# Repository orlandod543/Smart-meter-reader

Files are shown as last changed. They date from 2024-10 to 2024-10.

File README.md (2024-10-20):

# **P1 Reader Board for Smart Meters**

This is a P1 reader board that I built to measure electricity and gas from smart meters typically found in the Netherlands. It is designed to be a simple, DIY alternative to commercially available devices, fully compatible with Home Assistant and ESPHome, while being easy to assemble at home.

## **Key Features**
- **Powered directly by the smart meter**: No external power supply is needed; the board is powered from the P1 port of your meter.
- **Wi-Fi Connectivity**: The board connects to your local network via Wi-Fi.
- **Home Assistant Integration**: The design is fully compatible with Home Assistant for easy monitoring and automation.
- **ESPHome Compatibility**: It uses the DSMR (Dutch Smart Meter Requirements) component of ESPHome for simple configuration.
- **Easy DIY Assembly**: The PCB is designed for ease of assembly, allowing you to solder it at home in a few hours.

Additionally, the board includes an optional **DHT22 sensor** to monitor the temperature and humidity inside your electrical cabinet.

At the moment an example of the script to be used is not in this repository. Please go to https://esphome.io/components/sensor/dsmr.html for more details on how to create it. 

## **Getting Started**
- Assemble the PCB using the provided schematics.
- Create a ESPHome script following the instructions here: https://esphome.io/components/sensor/dsmr.html
- Flash the ESPHome firmware with your network details.
- Integrate with Home Assistant or any other compatible home automation platform.

## **License Information**

This hardware design is licensed under the **CERN Open Hardware License Strongly Reciprocal (CERN-OHL-S) v2.0**. This ensures that all modifications and derivative works are shared under the same open-source terms.

### **Summary of License Terms**
1. **You are free to**:
   - Use the design files for any purpose.
   - Modify the design, as long as you share your modifications under the same license.
   - Manufacture products based on this design.

2. **Conditions**:
   - You must give appropriate credit, including a link to the original design and this license.
   - If you modify the design and distribute the modified work (either as hardware or design files), you must share the modifications under the same license.

3. **Limitations**:
   - This license ensures that any modifications or derivatives of this design remain open-source.

For the full terms, please refer to the LICENSE.txt file.

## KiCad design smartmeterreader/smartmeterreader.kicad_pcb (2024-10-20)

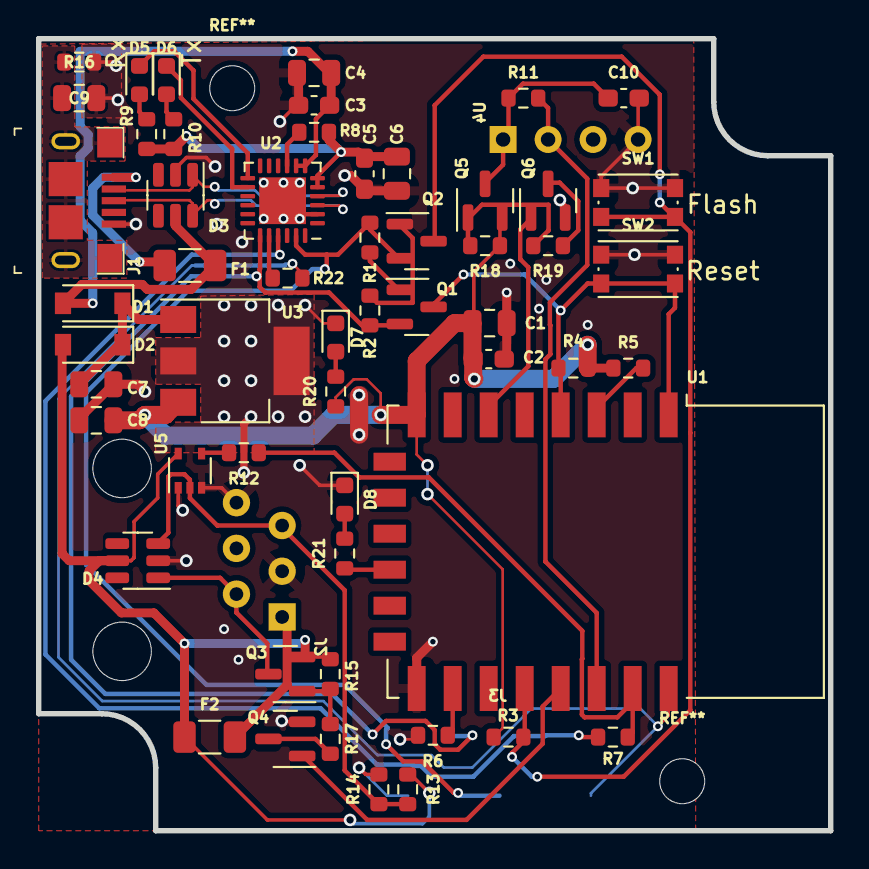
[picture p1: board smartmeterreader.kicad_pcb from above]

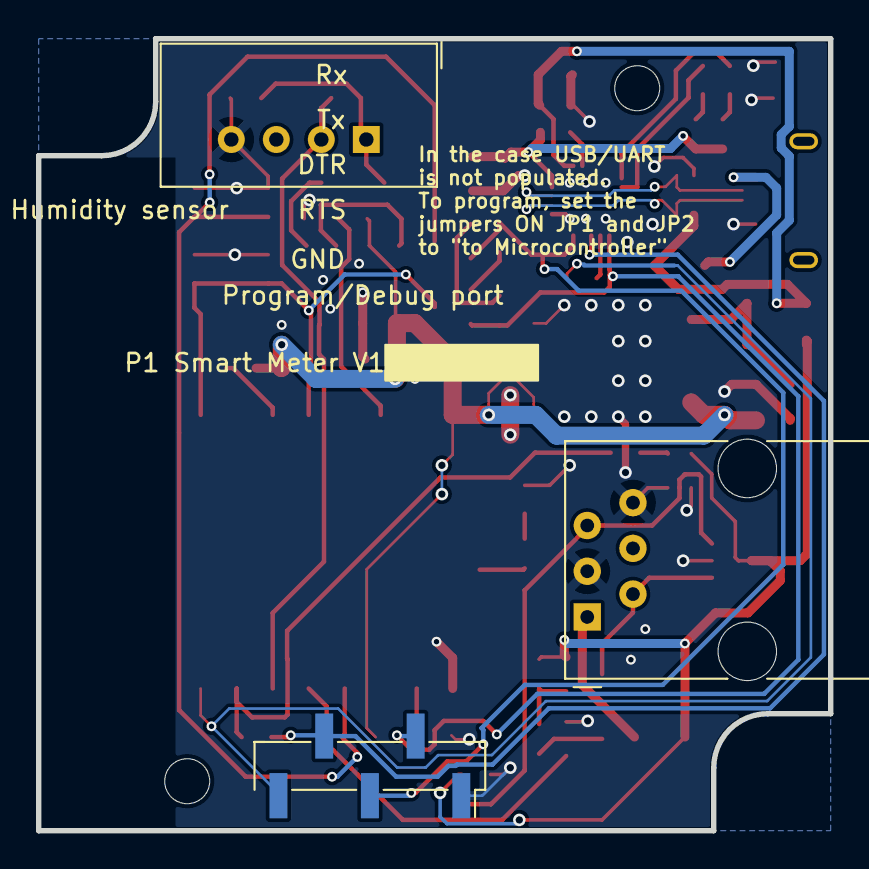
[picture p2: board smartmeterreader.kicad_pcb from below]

Board: 4 copper layers, 44.0 x 44.0 mm, 58 parts (3 on the bottom side), 42 nets.

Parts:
C1, C7, C8: 10uF; C_0805_2012Metric
C2, C3, C5: 100nF; C_0603_1608Metric_Pad1.08x0.95mm_HandSolder
C4, C6: 4.7uF; C_0805_2012Metric
C9: 4.7nF_250V; C_0805_2012Metric
C10: 1uF; C_0603_1608Metric_Pad1.08x0.95mm_HandSolder
D1, D2: PMEG2010ER; D_SOD-123
D3, D4: RCLAMP0504S; SOT-23-6
D5, D6, D7, D8: Green; LED_0603_1608Metric
F1, F2: 1A; Fuse_1206_3216Metric
J1: USB_B_Micro_RA; USB_Micro_B_Female_10118193-0001LF
J2: RJ12; RJ12_Amphenol_54601
J3: 1X05pin_2.54mm_smd; PinHeader_1x05_P2.54mm_Vertical_SMD_Pin1Right
Q1, Q2, Q4, Q6: 2N7002NXBK; SOT-23
Q3, Q5: PMV75UP; SOT-23
R1, R2, R3, R4, R5, R6, R11, R12, R13, R15, R18: 10K; R_0603_1608Metric
R7, R17, R19, R22: 100R; R_0603_1608Metric
R8, R9, R10, R20, R21: 1K; R_0603_1608Metric
R14: 15K; R_0603_1608Metric
R16: 1M; R_0603_1608Metric
SW1, SW2: SPST_NO; SW_Push_1P1T_NO_CK_KMR2
U1: ESP-12F; ESP-12E
U2: CP2102N-A02-GQFN24; QFN-24-1EP_4x4mm_P0.5mm_EP2.6x2.6mm
U3: MCP1824S-3V3; SOT-223-3_TabPin2
U4: DHT22; DHT22_7.7x15.1_P2mm
U5: 74HC1G02GW; SOT-353_SC-70-5

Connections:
+3V3: C1.1, C2.1, C8.1, Q5.2 (S), R3.1, R4.1, R5.1, R18.1, R20.1, U1.8 (VCC), U3.3 (Vout)
/5V_USB: C3.1, C4.1, D1.2 (A), D3.5 (K5), F1.2, U2.7 (VREGIN), U2.8 (VBUS)
/5V_meter: D2.2 (A), D4.5 (K5), F2.1, Q3.2 (S), R13.1, R15.1, U5.5 (VCC)
/D+: D3.6 (K6), J1.3 (D+), U2.3 (D+)
/D-: D3.1 (K1), J1.2 (D-), U2.4 (D-)
/DATA_LINE: D4.3 (K3), J2.5, R13.2, R14.1, U5.2 (A)
/DATA_REQ: D4.1 (K1), J2.2, Q3.3 (D)
/DHT22_DATA: R11.2, U1.20 (GPIO5), U4.2 (Data)
/DHT22_EN: Q6.1 (G), U1.6 (GPIO12)
/Data_Req_TTL: Q4.1 (G), U1.19 (GPIO4)
/Data_line_TTL: R7.1, R12.1, U1.21 (GPIO3/RXD)
/GPIO0: Q2.3 (D), R3.2, SW1.2 (B), U1.18 (GPIO0)
/High_side_SW.sch/VOut: C10.1, Q5.3 (D), R11.1, U4.1 (VDD)
/Power_supply_LDO_3V3/Vin: C7.1, D1.1 (K), D2.1 (K), U3.1 (Vin)
/UART_DTR: J3.3, Q2.2 (S), R1.2, U2.23 (DTR)
/UART_RTS: J3.2, Q1.2 (S), R2.2, U2.19 (RTS)
/UART_RX: J3.5, R22.2, U1.22 (GPIO1/TXD)
/UART_TX: J3.4, R7.2, U2.21 (TXD)
/USB-UART-transceiver/3.3V: C5.1, C6.1, R8.1, R9.1, R10.1, U2.5 (VIO), U2.6 (VDD)
/USB-UART-transceiver/UART_RX: R22.1, U2.20 (RXD)
/nRST: Q1.3 (D), R4.2, SW2.2 (B), U1.1 (~RST), U1.4 (GPIO16)
Earth: C9.1, J1.SH (Shield), R16.1
GND: C1.2, C2.2, C3.2, C4.2, C5.2, C6.2, C7.2, C8.2, C9.2, C10.2, D3.2 (A), D4.2 (A), D7.1 (K), D8.1 (K), J1.5 (GND), J2.3, J2.6, J3.1, Q4.2 (S), Q6.2 (S), R6.2, R14.2, R16.2, SW1.1 (A), SW2.1 (A), U1.15 (GND), U2.2 (GND), U2.25 (GND), U3.2 (GND), U4.4 (GND), U5.1 (B), U5.3 (GND)
unnamed: D5.1 (K), U2.13 (GPIO.1/RXT)
unnamed: D5.2 (A), R9.2
unnamed: D6.1 (K), U2.14 (GPIO.0/TXT)
unnamed: D6.2 (A), R10.2
unnamed: D7.2 (A), R20.2
unnamed: D8.2 (A), R21.2
unnamed: F1.1, J1.1 (VBUS)
unnamed: F2.2, J2.1
unnamed: Q1.1 (G), R1.1
unnamed: Q2.1 (G), R2.1
unnamed: Q3.1 (G), R15.2, R17.1
unnamed: Q4.3 (D), R17.2
unnamed: Q5.1 (G), R18.2, R19.1
unnamed: Q6.3 (D), R19.2
unnamed: R5.2, U1.3 (EN)
unnamed: R6.1, U1.16 (GPIO15)
unnamed: R8.2, U2.9 (~RSTb)
unnamed: R12.2, U5.4 (Y)
unnamed: R21.1, U1.12 (GPIO10)

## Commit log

2021-12-13 Draft design
    [Power_supply_LDO_3V3.sch, USB-UART-transceiver.sch, smartmeterreader.kicad_pcb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]
2021-12-16 Initial version of the smart meter. -Needs compoonent review, - Needs schematics review - No layout
    [High_side_SW.sch, P1_Interface.sch, Power_supply_LDO_3V3.sch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]
2022-09-24 Sync PCB with schematics
    [High_side_SW.kicad_sch, Power_supply_LDO_3V3.kicad_sch, USB-UART-transceiver.kicad_sch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]
2024-10-20 Add readme, licensing and a little bit more information about the case
    [Power_supply_LDO_3V3.kicad_sch, smartmeterreader.kicad_pcb]
